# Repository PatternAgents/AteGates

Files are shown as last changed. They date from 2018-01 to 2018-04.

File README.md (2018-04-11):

# AteGates { ERA : Eight (8) Gate I/O with 3.5mm Jacks } 



Format : ERA / Eurorack / Breadboard Friendly

Height : 1U 

Width: 16HP

Depth : 1.0 cm

Power : +12V 20mA

AteGates (pronounced as "Eight Gates") is a simple eight (8) bit I/O module,
where any Gate (Jack) can either be an input or an output.
Eight (8) LED's indicate the state of the Gate, and Eight (8) Pushbuttons allow
for manual playing and testing of each Gate.

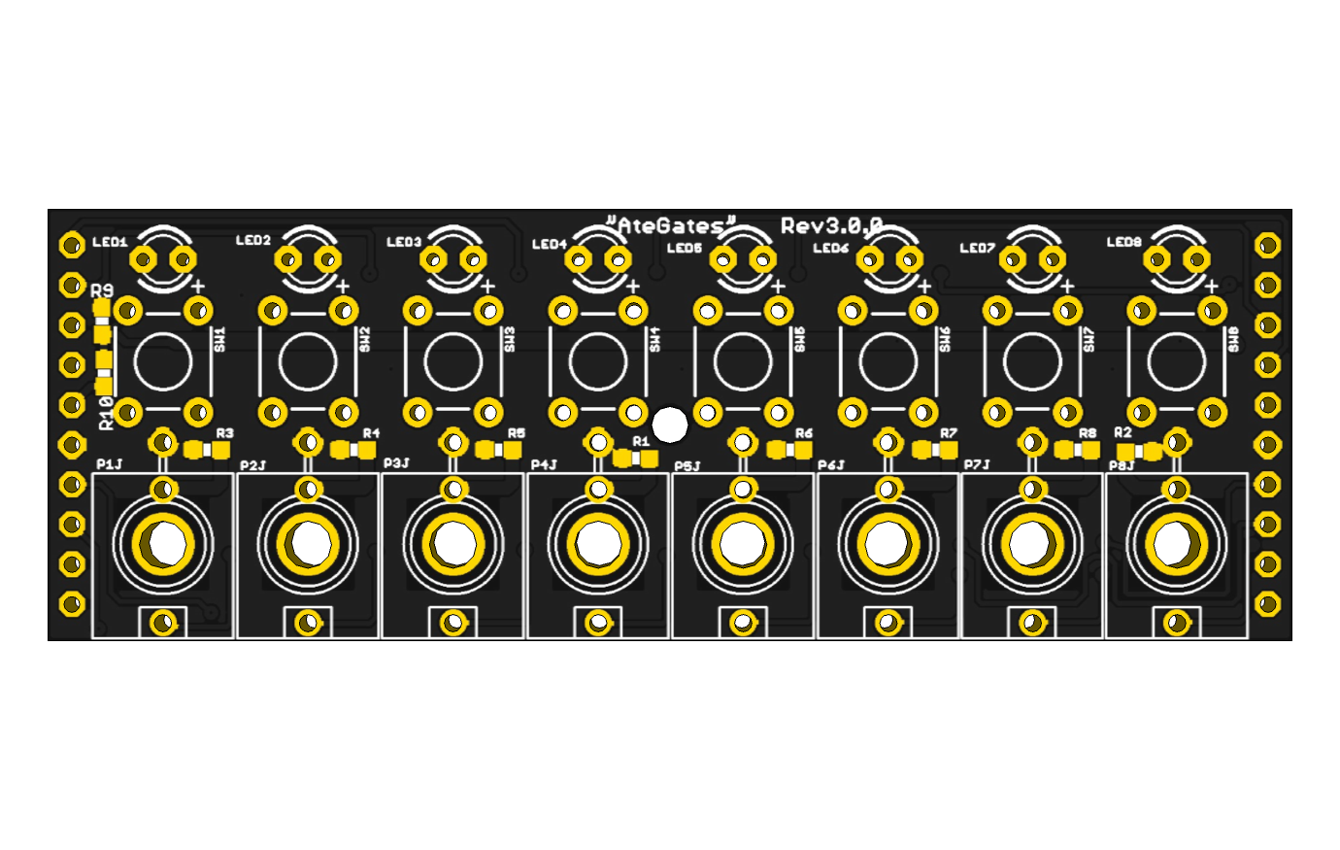
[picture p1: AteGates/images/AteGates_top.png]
thingSoC AteGates
[AteGates](https://github.com/patternagents/AteGates)

AteGates can be used on a breadboard for prototyping new circuits,
or it can mounted into a 1U Rack system using the following 1U x 16 HP front panel design.

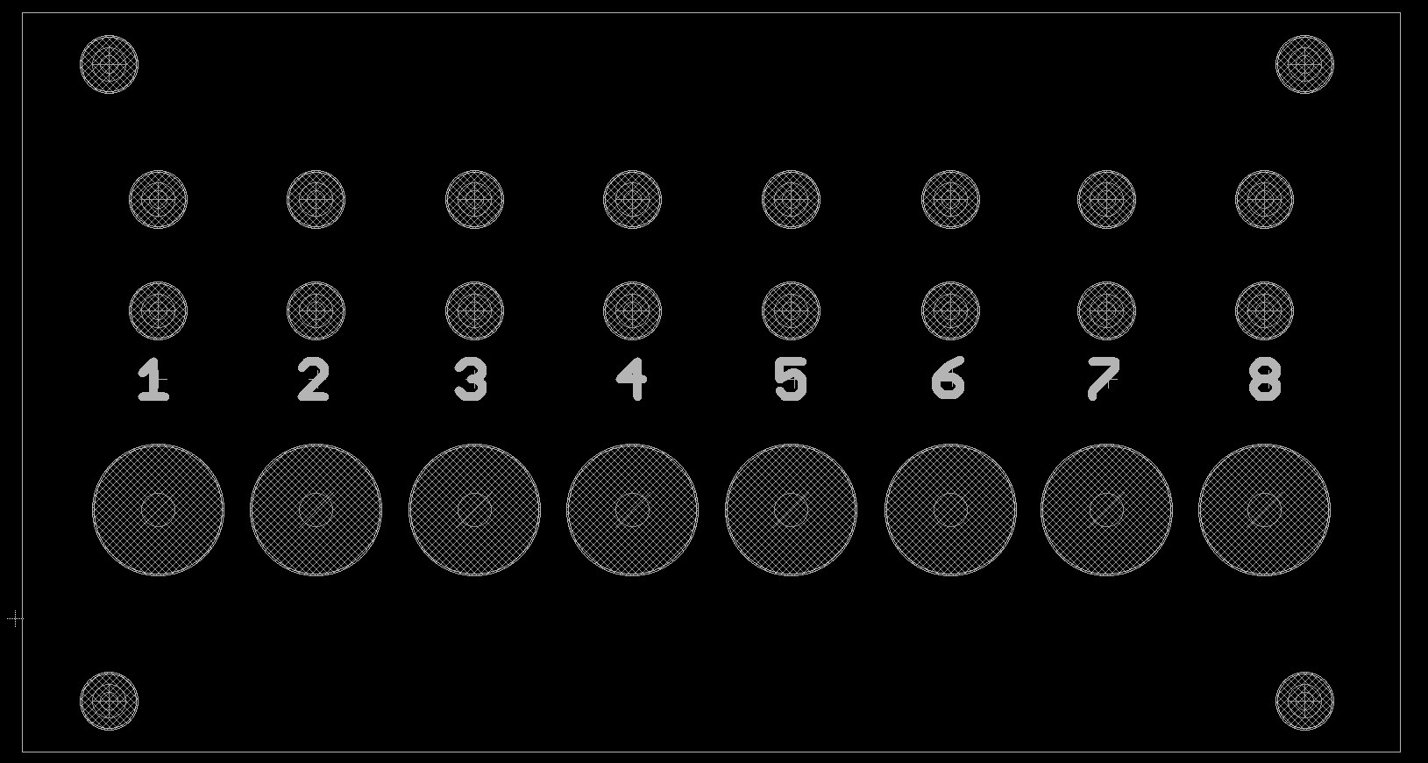
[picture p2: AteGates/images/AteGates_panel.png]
AteGates 1U Front Panel
[AteGates 1U Front Panel](https://github.com/patternagents/AteGates)

AteGates can be used in combination with two (2) or more other ERA modules
for mounting in a 3U ERA or Eurorack format card or even larger rack format
.
Any Jack/Gate can be configured to be either an input or an output (at build time),
by placing two (2) resistors in different places (as jumpers).

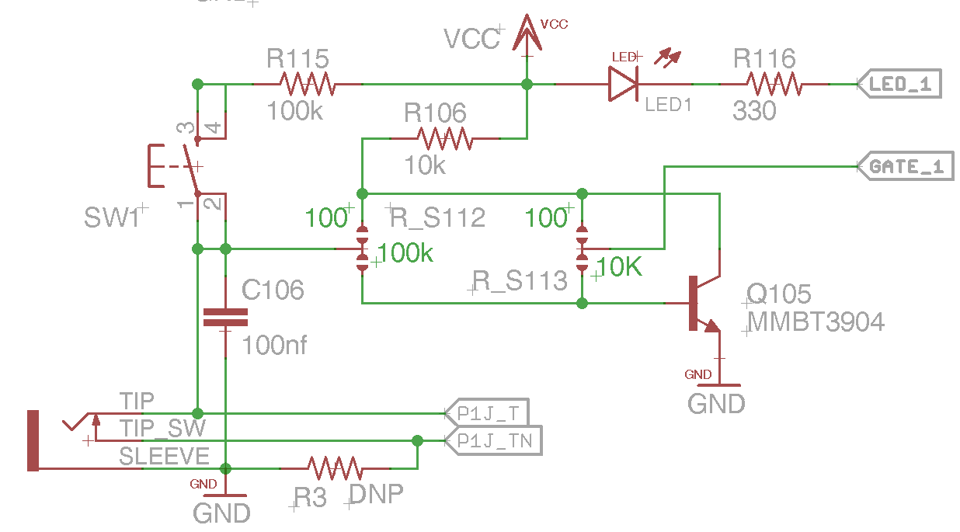
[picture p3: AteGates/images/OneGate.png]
AteGates One Gate
[AteGates One Gate](https://github.com/patternagents/AteGates)

Breadboard Use (Dual Width Breadboard)

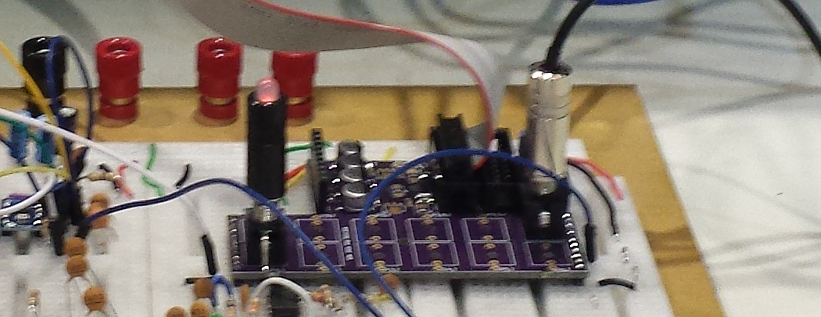
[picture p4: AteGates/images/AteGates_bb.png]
AteGates Breadboard
[AteGates Breadboard](https://github.com/patternagents/AteGates)

# Using AteGates

1) Breadboard : AteGates uses male pins on the bottom side of the PCB for breadboard applications.
2) thingSoC1UG : AteGates can plug into any thingSoC1UG (1U Gate) board for adding microprocessor interfaces like MIDI or OSC.

**thingSoC Reference Designs** are example thingSoC implementations that implement
various reference and testing circuits for demonstrating the use of the thingSoC libraries.
These reference designs can serve as starting templates for user designs.

---------------------------------------

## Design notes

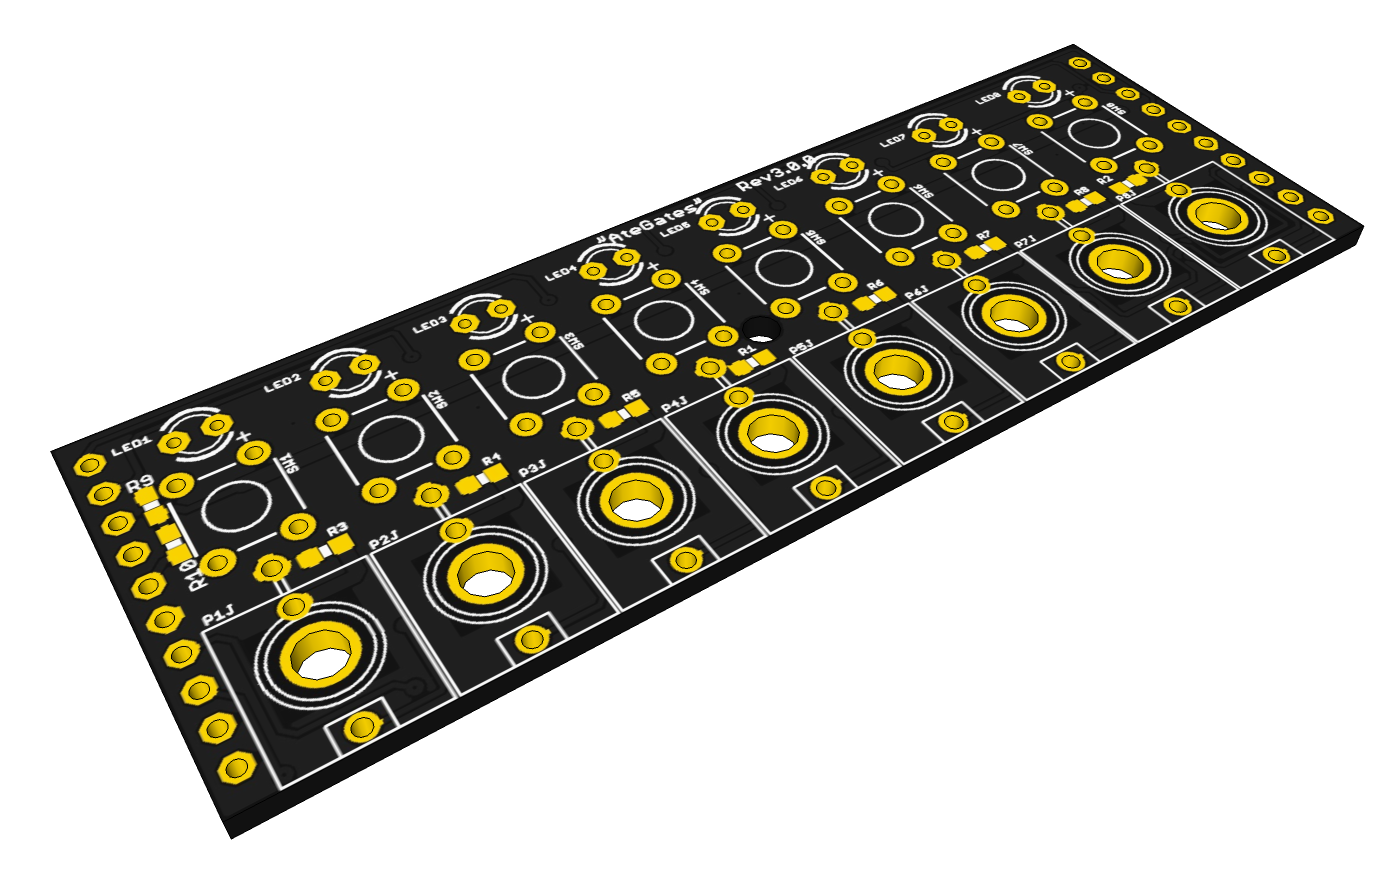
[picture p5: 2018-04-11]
AteGates/images/AteGates_iso.png

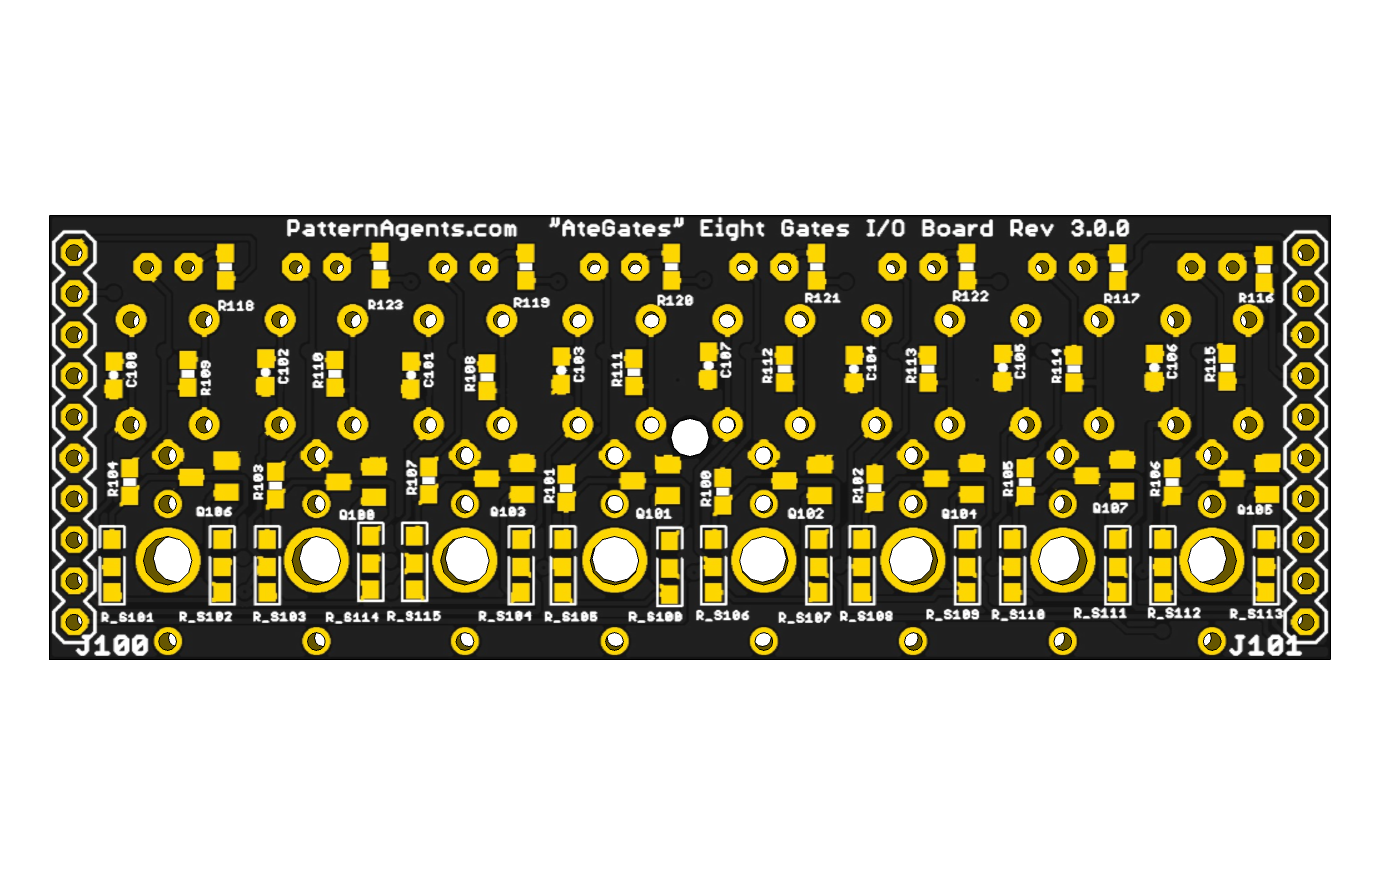
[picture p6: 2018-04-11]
AteGates/images/AteGates_bot.png

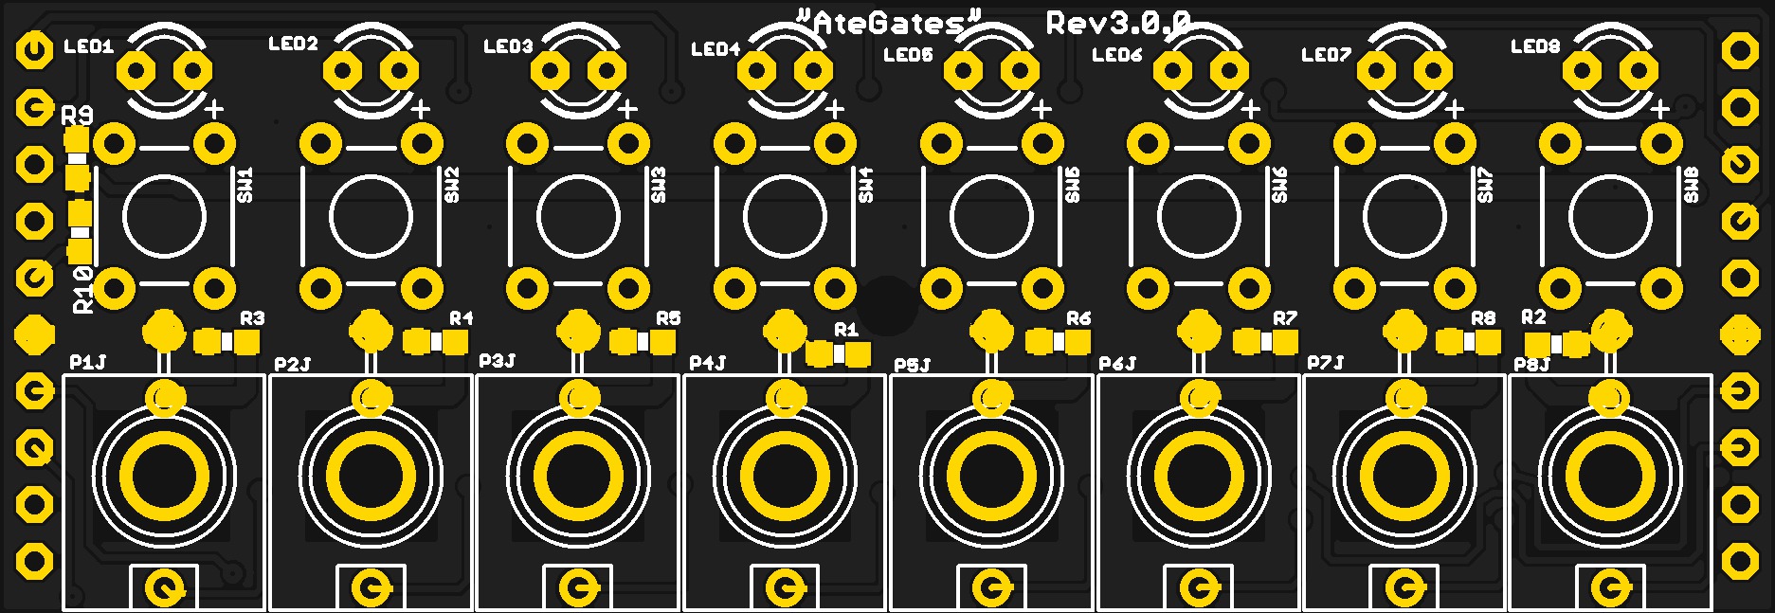
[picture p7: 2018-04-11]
AteGates/eagleUp/eagleUp_AteGates_board_top.jpg

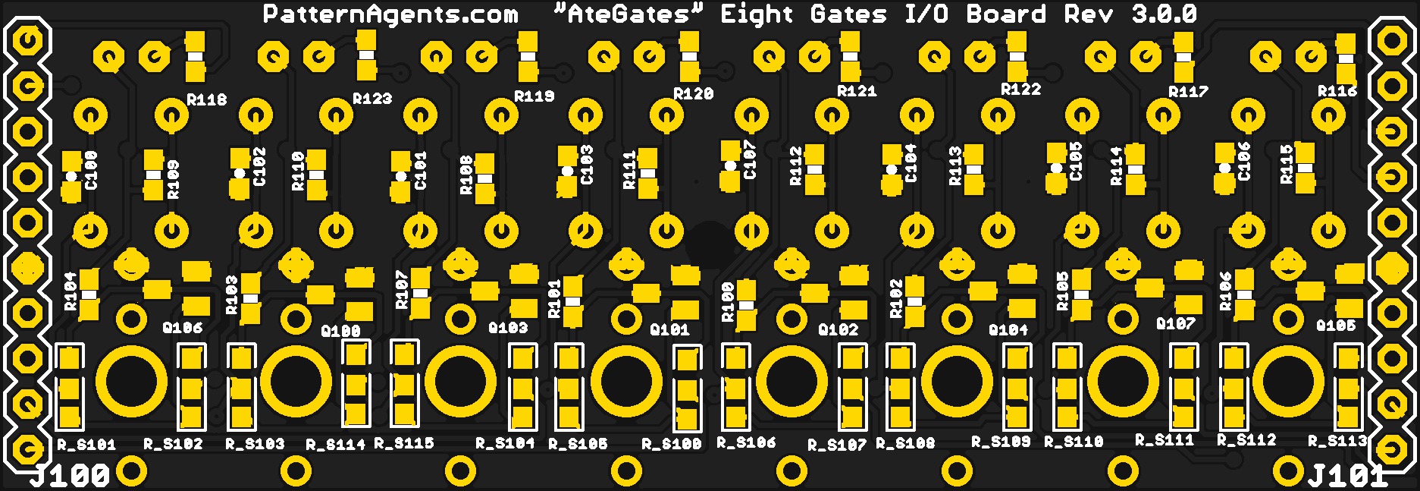
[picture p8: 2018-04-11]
AteGates/eagleUp/eagleUp_AteGates_board_bottom.jpg

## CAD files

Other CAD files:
AteGates/eagleUp/AteGates.skp

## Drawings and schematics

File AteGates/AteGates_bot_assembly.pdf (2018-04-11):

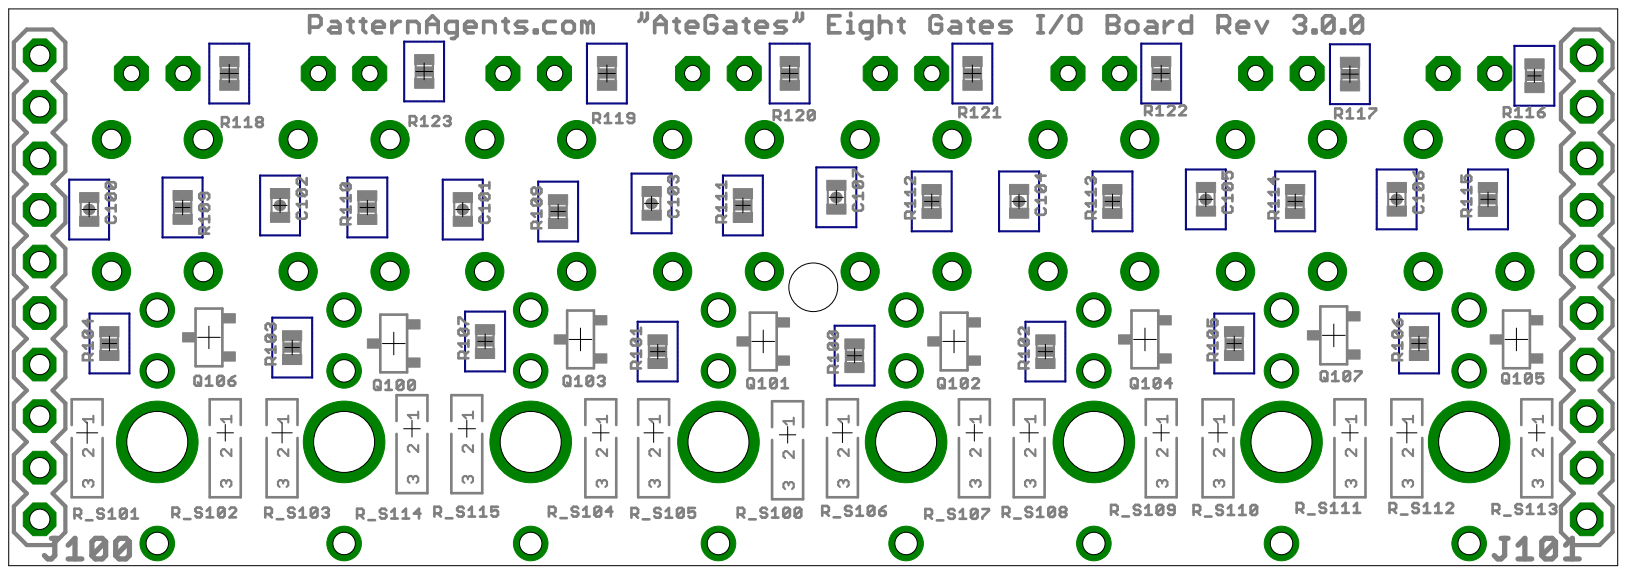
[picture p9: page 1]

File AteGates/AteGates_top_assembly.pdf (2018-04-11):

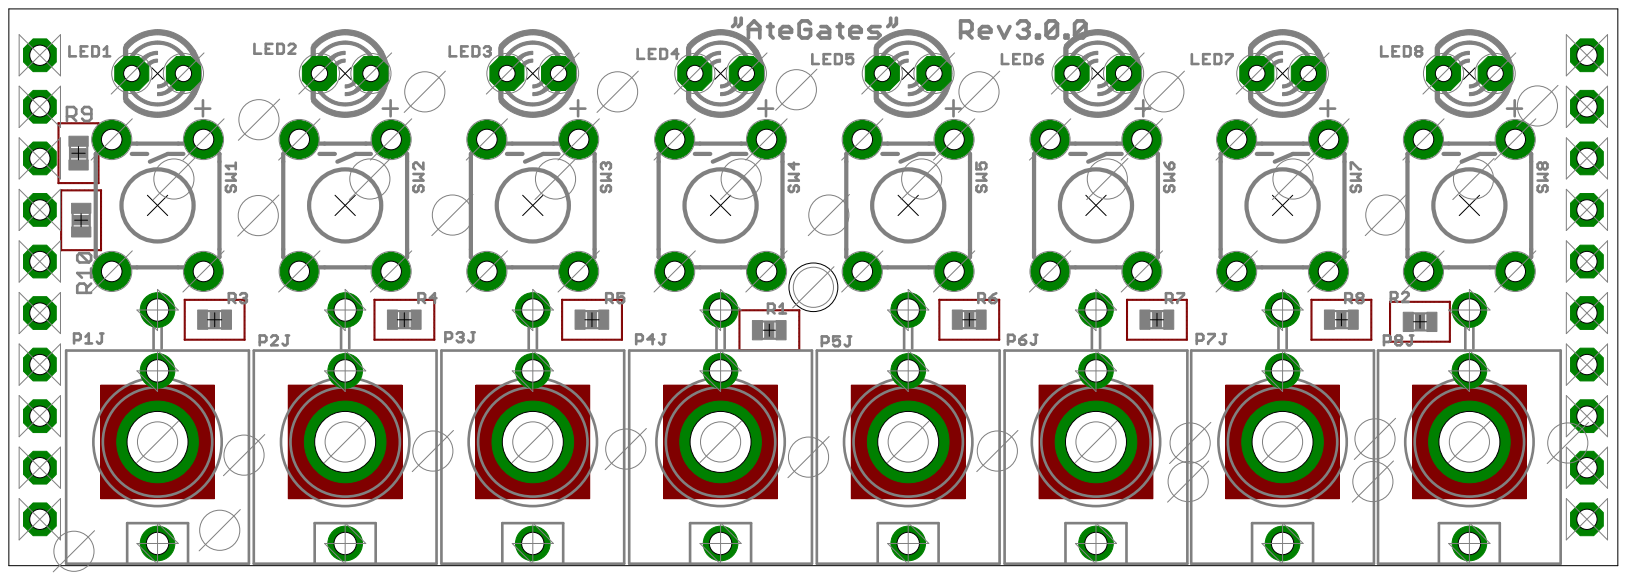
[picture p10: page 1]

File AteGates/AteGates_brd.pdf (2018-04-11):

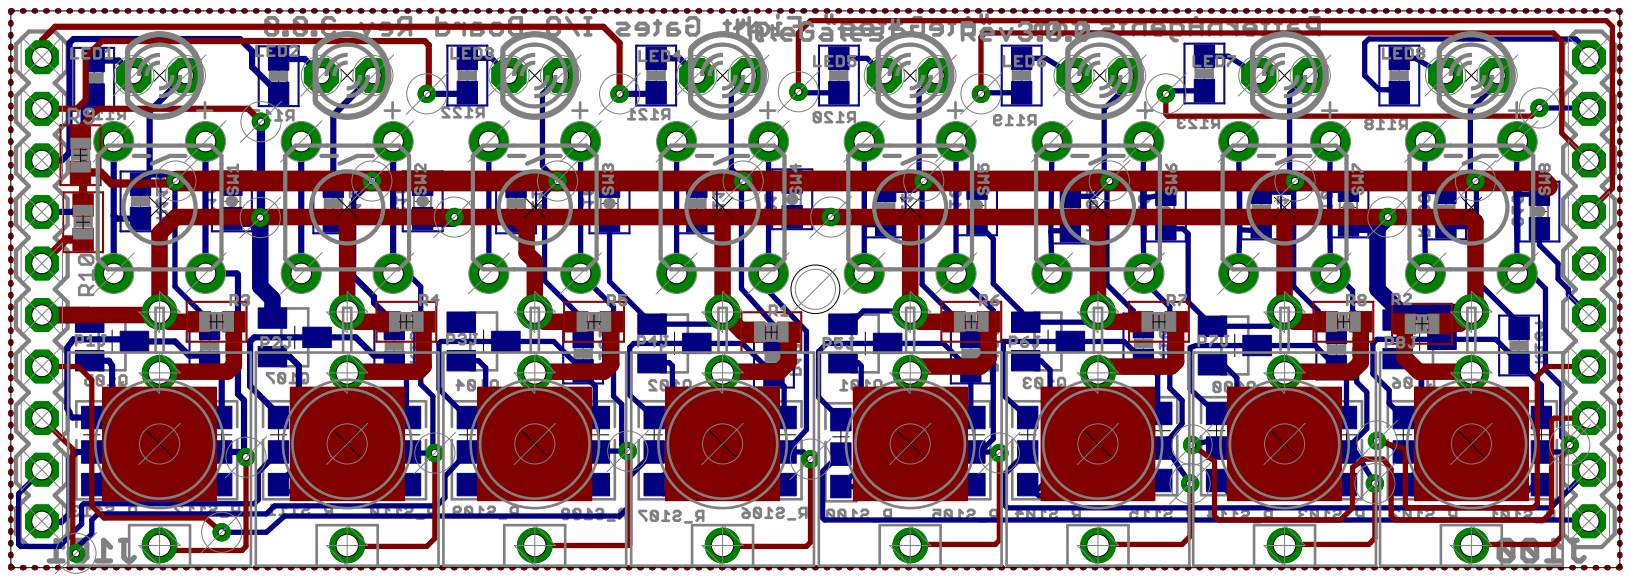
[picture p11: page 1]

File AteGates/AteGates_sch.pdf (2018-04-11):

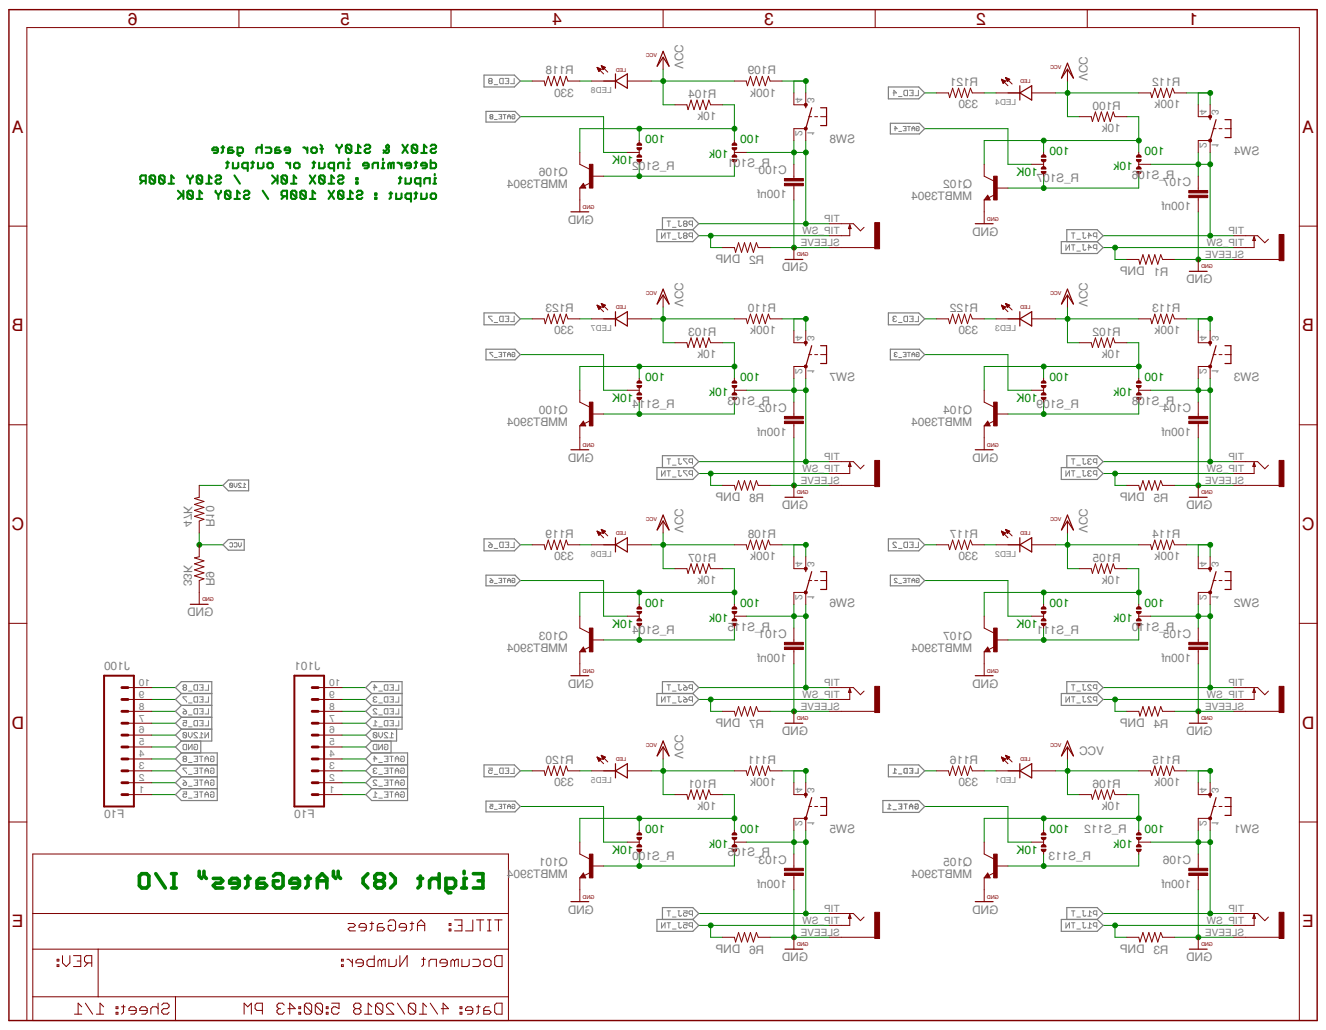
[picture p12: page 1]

k01 001 K01 001 k01 001 K01 001 k01 001 K01 001 k01 001 K01 001 k01 001 K01 001 k01 001 K01 001 k01 001 K01 001 k01 001 K01 001 ABCDE ABCDE 6 5 4 3 2 1DNG DNG DNG DNG DNG DNG DNG DNG DEL CCV DNG DEL CCV DNG DEL CCV DNG DEL CCV DNG DEL CCV DNG DEL CCV DNG DEL CCV DNG DEL CCV DNG DNG 101J 12345678901 001J 12345678901 EVEELS PI T WS_PI T EVEELS PI T WS_PI T EVEELS PI T WS_PI T EVEELS PI T WS_PI T EVEELS PI T WS_PI T EVEELS PI T WS_PI T EVEELS PI T WS_PI T EVEELS PI T WS_PI T 1DEL 1 43 2 1 WS 501 Q 601R 611R 511R 211S_R 311S_R 601C 2DEL 1 43 2 2 WS 701 Q 501R 711R 411R 111S_R 011S_R501C 3DEL 1 43 2 3 WS 401 Q 201R 221R 311R 901S_R 801S_R401C 4DEL 1 43 2 4 WS 201 Q 001R 121R 211R 701S_R 601S_R701C 5DEL 1 43 2 5 WS 101 Q 101R 021R 111R 001S_R 501S_R301C 3R4R5R1R 6R7R8R2R 6DEL 1 43 2 6 WS 301 Q 701R 911R 801R 401S_R 511S_R101C 7DEL 1 43 2 7 WS 001 Q 301R 321R 011R 411S_R 301S_R201C 8DEL 1 43 2 8 WS 601 Q 401R 811R 901R 201S_R 101S_R001C R9 R10 01F 01F DNG DNG DNG DNG DNG DNG DNG DNG 4093TB MM k01 CCV 033 k001 DNG f n001 4093TB MM k01 VCC 033 k001 DNG f n001 4093TB MM k01 VCC 033 k001 DNG f n001 4093TB MM k01 VCC 033 k001 DNG f n001 4093TB MM k01 VCC 033 k001 DNG f n001 PND PND PND PND PND PND PND PND 4093TB MM k01 VCC 033 k001 DNG f n001 4093TB MM k01 VCC 033 k001 DNG f n001 4093TB MM k01 VCC 033 k001 DNG f n001 33K 47K DNG

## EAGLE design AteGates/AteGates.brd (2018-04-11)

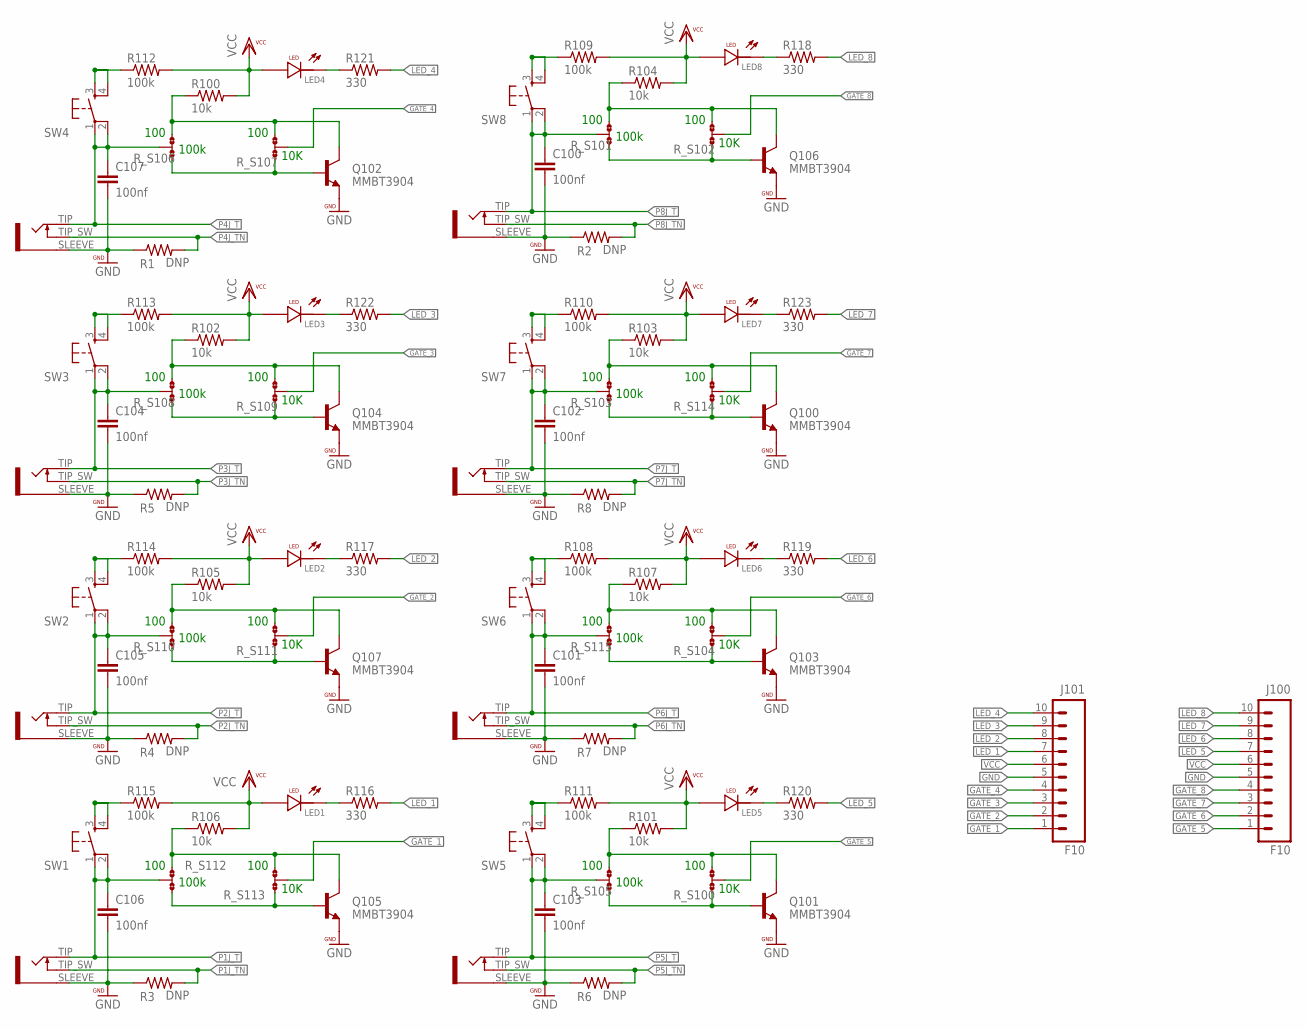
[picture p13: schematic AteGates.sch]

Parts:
C100, C101, C102, C103, C104, C105, C106, C107: 100nf; 0603-CAP
J100, J101: F10; 1X10_OCTO
LED1, LED2, LED3, LED4, LED5, LED6, LED7, LED8: LED; LED3MM
P1J, P2J, P3J, P4J, P5J, P6J, P7J, P8J: JACK-3_5MM-MONO-SW-WQP_PJ302-12; WQP_PJ301M-12
Q100, Q101, Q102, Q103, Q104, Q105, Q106, Q107: MMBT3904; SOT23-BEC
R1, R2, R3, R4, R5, R6, R7, R8: DNP; 0603-RES
R100, R101, R102, R103, R104, R105, R106, R107: 10k; 0603-RES
R108, R109, R110, R111, R112, R113, R114, R115: 100k; 0603-RES
R116, R117, R118, R119, R120, R121, R122, R123: 330; 0603-RES
R_S100, R_S102, R_S104, R_S107, R_S109, R_S111, R_S113, R_S114: JMP-3-NO-0603
R_S101, R_S103, R_S105, R_S106, R_S108, R_S110, R_S112, R_S115: 100; JMP-3-NO-0603
SW1, SW2, SW3, SW4, SW5, SW6, SW7, SW8: TAC_SWITCHPTH; TACTILE-PTH

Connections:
GATE_1: J101.1, R_S113.2
GATE_2: J101.2, R_S111.2
GATE_3: J101.3, R_S109.2
GATE_4: J101.4, R_S107.2
GATE_5: J100.1, R_S100.2
GATE_6: J100.2, R_S104.2
GATE_7: J100.3, R_S114.2
GATE_8: J100.4, R_S102.2
GND: C100.2, C101.2, C102.2, C103.2, C104.2, C105.2, C106.2, C107.2, J100.5, J101.5, P1J.SLEEVE, P2J.SLEEVE, P3J.SLEEVE, P4J.SLEEVE, P5J.SLEEVE, P6J.SLEEVE, P7J.SLEEVE, P8J.SLEEVE, Q100.E, Q101.E, Q102.E, Q103.E, Q104.E, Q105.E, Q106.E, Q107.E, R1.1, R2.1, R3.1, R4.1, R5.1, R6.1, R7.1, R8.1; also elsewhere on the board
GTI_1_LEDK: LED1.K (CATHODE), R116.1
GTI_1_LEDK1: LED2.K (CATHODE), R117.1
GTI_1_LEDK2: LED3.K (CATHODE), R122.1
GTI_1_LEDK3: LED4.K (CATHODE), R121.1
GTI_1_LEDK4: LED5.K (CATHODE), R120.1
GTI_1_LEDK5: LED6.K (CATHODE), R119.1
GTI_1_LEDK6: LED7.K (CATHODE), R123.1
GTI_1_LEDK7: LED8.K (CATHODE), R118.1
LED_1: J101.7, R116.2
LED_2: J101.8, R117.2
LED_3: J101.9, R122.2
LED_4: J101.10, R121.2
LED_5: J100.7, R120.2
LED_6: J100.8, R119.2
LED_7: J100.9, R123.2
LED_8: J100.10, R118.2
P1J_T: C106.1, P1J.TIP, R_S112.2, SW1.1, SW1.2
P1J_TN: P1J.TIP_SW, R3.2
P2J_T: C105.1, P2J.TIP, R_S110.2, SW2.1, SW2.2
P2J_TN: P2J.TIP_SW, R4.2
P3J_T: C104.1, P3J.TIP, R_S108.2, SW3.1, SW3.2
P3J_TN: P3J.TIP_SW, R5.2
P4J_T: C107.1, P4J.TIP, R_S106.2, SW4.1, SW4.2
P4J_TN: P4J.TIP_SW, R1.2
P5J_T: C103.1, P5J.TIP, R_S105.2, SW5.1, SW5.2
P5J_TN: P5J.TIP_SW, R6.2
P6J_T: C101.1, P6J.TIP, R_S115.2, SW6.1, SW6.2
P6J_TN: P6J.TIP_SW, R7.2
P7J_T: C102.1, P7J.TIP, R_S103.2, SW7.1, SW7.2
P7J_TN: P7J.TIP_SW, R8.2
P8J_T: C100.1, P8J.TIP, R_S101.2, SW8.1, SW8.2
P8J_TN: P8J.TIP_SW, R2.2
Q1_B: Q105.B, R_S112.3, R_S113.3
Q1_B1: Q107.B, R_S110.3, R_S111.3
Q1_B2: Q104.B, R_S108.3, R_S109.3
Q1_B3: Q102.B, R_S106.3, R_S107.3
Q1_B4: Q101.B, R_S100.3, R_S105.3
Q1_B5: Q103.B, R_S104.3, R_S115.3
Q1_B6: Q100.B, R_S103.3, R_S114.3
Q1_B7: Q106.B, R_S101.3, R_S102.3
Q1_C: Q105.C, R106.1, R_S112.1, R_S113.1
Q1_C1: Q107.C, R105.1, R_S110.1, R_S111.1
Q1_C2: Q104.C, R102.1, R_S108.1, R_S109.1
Q1_C3: Q102.C, R100.1, R_S106.1, R_S107.1
Q1_C4: Q101.C, R101.1, R_S100.1, R_S105.1
Q1_C5: Q103.C, R107.1, R_S104.1, R_S115.1
Q1_C6: Q100.C, R103.1, R_S103.1, R_S114.1
Q1_C7: Q106.C, R104.1, R_S101.1, R_S102.1
SW1: R115.1, SW1.3, SW1.4
SW2: R114.1, SW2.3, SW2.4
SW3: R113.1, SW3.3, SW3.4
SW4: R112.1, SW4.3, SW4.4
SW5: R111.1, SW5.3, SW5.4
SW6: R108.1, SW6.3, SW6.4
SW7: R110.1, SW7.3, SW7.4
SW8: R109.1, SW8.3, SW8.4

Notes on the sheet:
100k
100
10K

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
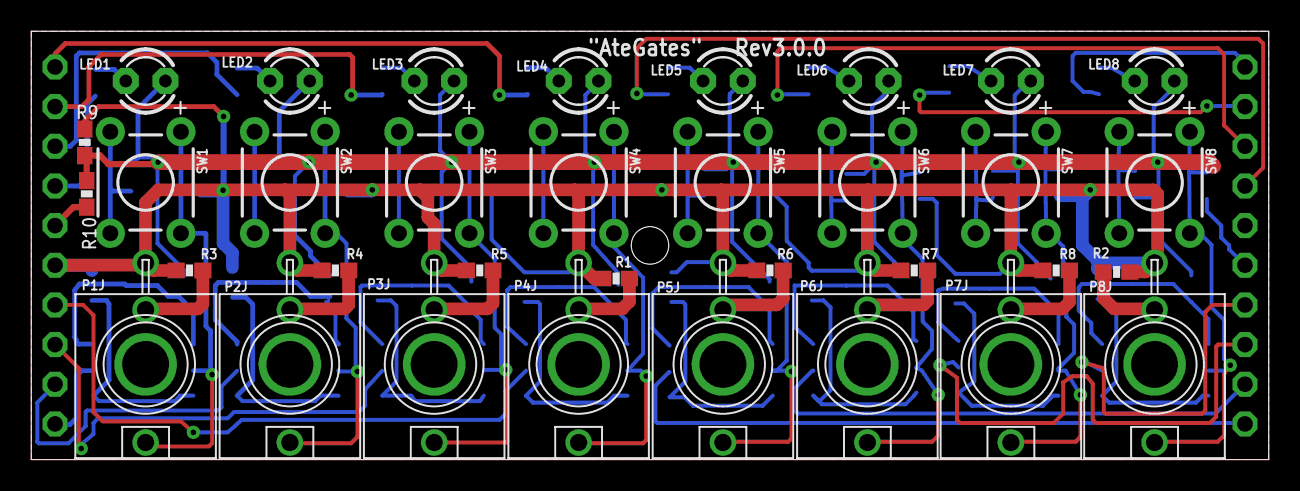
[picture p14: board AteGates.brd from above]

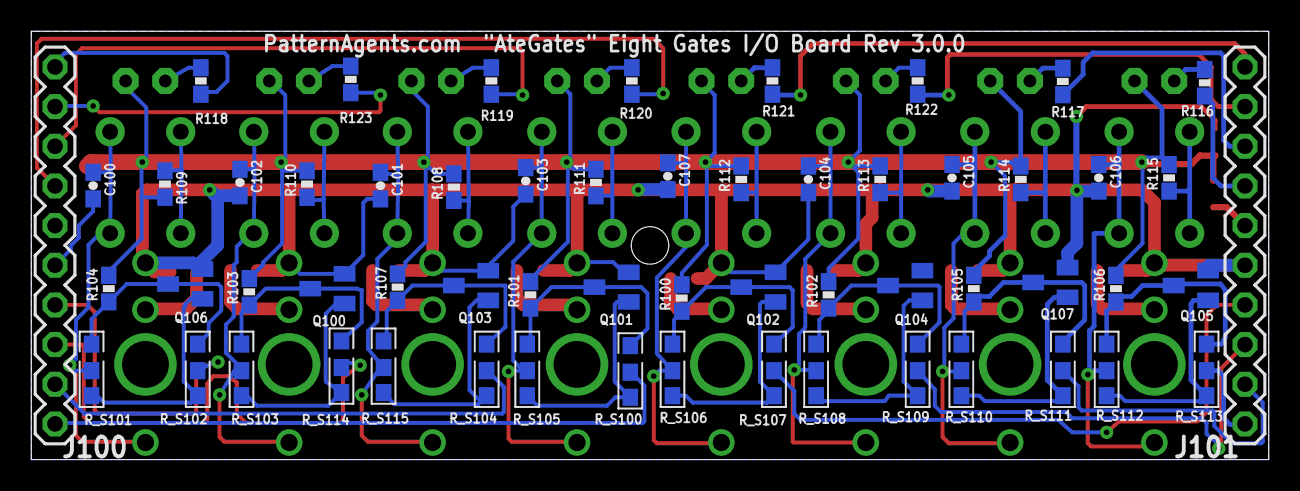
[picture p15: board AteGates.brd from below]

Board: 2 copper layers, 79.2 x 27.4 mm, 92 parts (58 on the bottom side), 67 nets.

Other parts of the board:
R9: 33K; 0603-RES
R10: 47K; 0603-RES

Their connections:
GND: R9.1; also elsewhere on the board

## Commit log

2018-01-20 initial revision
    [AteGates.brd, AteGates.sch, AteGates.skp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]
2018-01-21 add images
    [AteGates.sch, AteGates_panel.brd, AteGates_panel.sch]
2018-01-21 fix directory structure, oops...
    [AteGates.brd, AteGates.sch, AteGates.skp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]
2018-04-11 4/10 update
    [AteGates.brd, AteGates.sch, AteGates.skp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]
2018-04-11 4/11 update
    [AteGates.brd]

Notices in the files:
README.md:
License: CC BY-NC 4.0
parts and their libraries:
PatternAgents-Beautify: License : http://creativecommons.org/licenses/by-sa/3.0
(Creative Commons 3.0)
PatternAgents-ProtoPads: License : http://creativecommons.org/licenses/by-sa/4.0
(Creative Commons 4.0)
